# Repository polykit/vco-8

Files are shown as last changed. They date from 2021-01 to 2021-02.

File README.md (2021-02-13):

# Polykit Octo VCO aka VCO-8

This repository contains Kicad schematics and PCB layout for an octo 1V/oct VCO. It is based on [this design](https://github.com/polykit/vco-1).

Here you can listen to some short examples how it sounds: [example 1](https://soundcloud.com/polykit/polykit-octo-vco) [example 2](https://soundcloud.com/polykit/polykit-oxcto-vco-2)

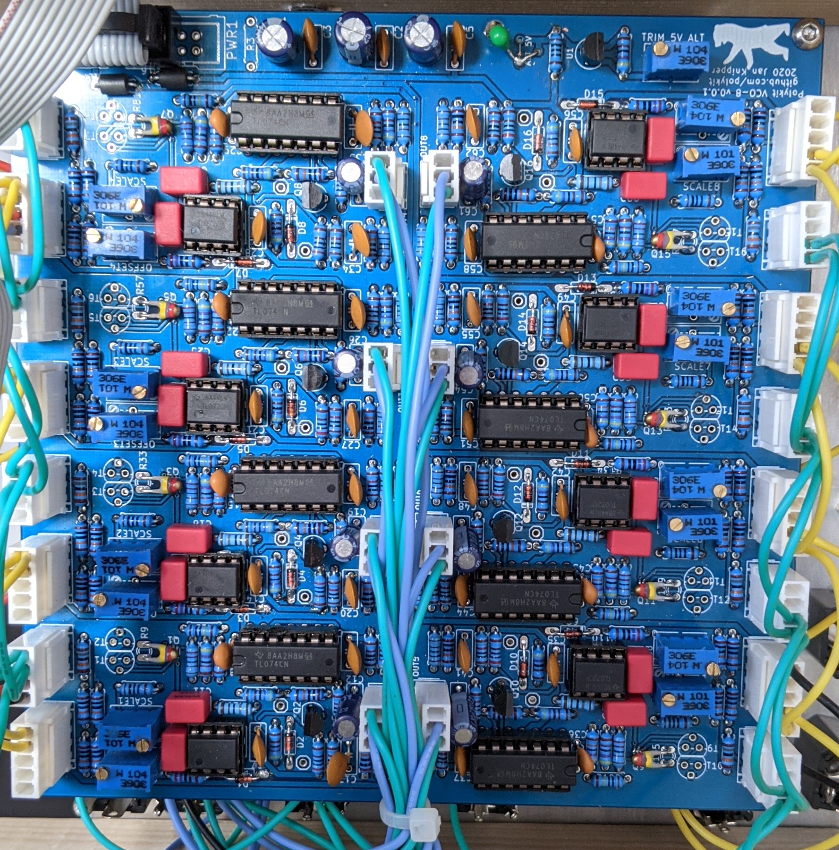
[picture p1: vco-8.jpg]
Polykit Octo VCO


# Building instructions

Building it is really straight forward. I suggest starting with components with the lowest height, eg. all SMD components, all diodes, all resistors and so on. Put all of one kind in place at the same time, eg. all 100k resistors. This helps to reduce problems while building it. If you want to try it out it is maybe a good idea to build the [single VCO](https://github.com/polykit/vco-1) version first.

You need either a pair of matched 2N3904s or one BC847BS transistor pair in a SMD package per VCO. I have very good tracking results with the BC847BS and not so good results with the 2N3904s. But maybe this is because of my poor matching. Bend the legs of the NTCs so that they are as close as possbile to the transistors.

## Powering

There are two powering options. First is 16-pin Eurorack with +12V, -12V and +5V. Second one is a 10-pin Eurorack with +12V and -12V and an additional TL431 for precise +5V supply. Make sure to put a jumper to `5V_ALT` and leave out `R3` if you opted for the latter. There is a testpoint `TP` where you can measure while adjusting `TRIM_5V_ALT` to +5.00V. I recommend the second option because of it's precision.

## Tuning

Use the power supply that you are going to use later on for tuning. Otherwise you might need to tune it again. I used a tuning device for this but also a tuning app for your mobile will work just fine. This is how I tuned the oscillators:

* Turn it on and wait at least 15 minutes before you start tuning
* Tune all oscillators roughly to a base note, eg. `C4`. Do this by applying the correct CV input and adjusting the offset trim pot.
* Next is to get the right scale. Start with the first oscillator and adjust scale until you have the correct interval between two notes, eg. your base note `C4` and `D4`. While changing scale overall tuning will change, so go back to your base note from time to time by adjusting the offset. When your are quite close to the correct scale fine tune it for a whole ocatve, eg. using notes `C4` and `C5`. Proceed with the next oscillator.
* Start again with the first oscillator until everything is in tune. Usually you only need to adjust offset for this.

## Tweaks

* Use ferrite beads or just jumpers instead of the 10R resistors for R3, R4 and R5. There is a significant voltage drop over the resistors leading to a lower peak-to-peak amplitude.
* Use 22µ polarized caps instead of 1µ non-polarized ones. The positive side (+) of the cap is torwards the op-amp and negative (-) to the output. I had the impression that it gives you a nicer ramp signal on the output.

## BOM

|Designator|Quantity |Designation|
|---|---|---|
|U1 |1 |TL431LP*** |
|TRIM_5V_ALT, OFFSET8, OFFSET7, OFFSET6, OFFSET5, OFFSET4, OFFSET3, OFFSET2, OFFSET1|9 |100k |
|R197, R36, R180, R156, R132, R108, R84, R60, R12|9 |47k |
|R196, R182, R158, R134, R110, R86, R62, R38, R14|9 |270 |
|C16, C21, C58, C56, C51, C49, C44, C42, C37, C35, C30, C28, C14, C2, C5, C3, C23, C7, C9|19 |100n |
|C22, C57, C50, C43, C36, C29, C15, C8|8 |1n |
|R50, R195, R194, R171, R170, R147, R146, R123, R122, R99, R98, R75, R74, R51, R27, R26|16 |1k |
|R33, R177, R153, R129, R105, R81, R57, R9|8 |4k7 NTC |
|T16, T15, T14, T13, T12, T11, T10, T9, T8, T7, T6, T5, T4, T3, T1, T2|16 |2N3904* |
|SCALE8, SCALE7, SCALE6, SCALE5, SCALE4, SCALE3, SCALE2, SCALE1|8 |100 |
|R193, R184, R175, R174, R173, R172, R169, R160, R151, R150, R149, R148, R145, R136, R127, R126, R125, R124, R121, R112, R103, R102, R101, R100, R97, R88, R79, R78, R77, R76, R73, R64, R55, R31, R30, R54, R53, R52, R49, R40, R29, R28, R6, R7, R2, R16, R1, R25|48 |100k |
|R192, R186, R176, R168, R162, R152, R144, R138, R128, R120, R114, R104, R96, R90, R80, R72, R66, R56, R32, R48, R42, R24, R8, R18|24 |4k7 |
|R191, R189, R187, R167, R165, R163, R143, R141, R139, R119, R117, R115, R95, R93, R91, R71, R69, R67, R47, R45, R43, R19, R21, R23|24 |10k |
|R190, R166, R142, R118, R94, R70, R46, R22|8 |2k |
|R188, R164, R140, R116, R92, R68, R44, R20|8 |1k8 |
|R185, R161, R137, R113, R89, R65, R41, R17|8 |470k |
|R183, R159, R135, R111, R87, R63, R39, R15|8 |180k |
|R181, R157, R133, R109, R85, R61, R37, R13|8 |1M |
|R179, R155, R131, R107, R83, R59, R35, R11|8 |100* |
|R178, R154, R130, R106, R82, R58, R34, R10|8 |2k2 |
|Q16, Q14, Q12, Q10, Q8, Q6, Q4, Q2|8 |BS170 |
|Q15, Q13, Q11, Q9, Q7, Q5, Q3, Q1|8 |BC847BS* |
|IC16, IC14, IC12, IC10, IC8, IC6, IC2, IC4|8 |TL072P |
|IC15, IC13, IC11, IC9, IC7, IC5, IC1, IC3|8 |TL074P |
|D16, D15, D14, D13, D12, D11, D10, D9, D8, D7, D6, D5, D4, D3, D2, D1|16 |1N4148 |
|C62, C55, C48, C41, C34, C27, C20, C13|8 |10n |
|C61, C54, C47, C40, C33, C19, C26, C12|8 |1µ** |
|C60, C53, C46, C39, C32, C18, C25, C11|8 |100p** |
|C59, C52, C45, C38, C31, C17, C24, C10|8 |1n** |
|C6, C4, C1  |3 |10µ polarized |
|R4, R5, R3  |3 |10 |
|PWR1 |1 |ML16 or ML10***| 

\* Use either matched pairs of 2N3904s or BC847BS dual transistors. Use 120R instead of 100R for R179, R155, R131, R107, R83, R59, R35 and R11 when you are going for the 2N3904s.

\** Use polypropylene or similar caps

\*** See powering options. Leave out U1, R196, R197 and TRIM_5V_ALT if you opted for 16-pin Eurorack supply with +5V in place.

# References

https://github.com/polykit/vco-1

https://www.diodes.com/assets/Datasheets/ds30222.pdf

https://www.ti.com/lit/ds/symlink/tl431.pdf

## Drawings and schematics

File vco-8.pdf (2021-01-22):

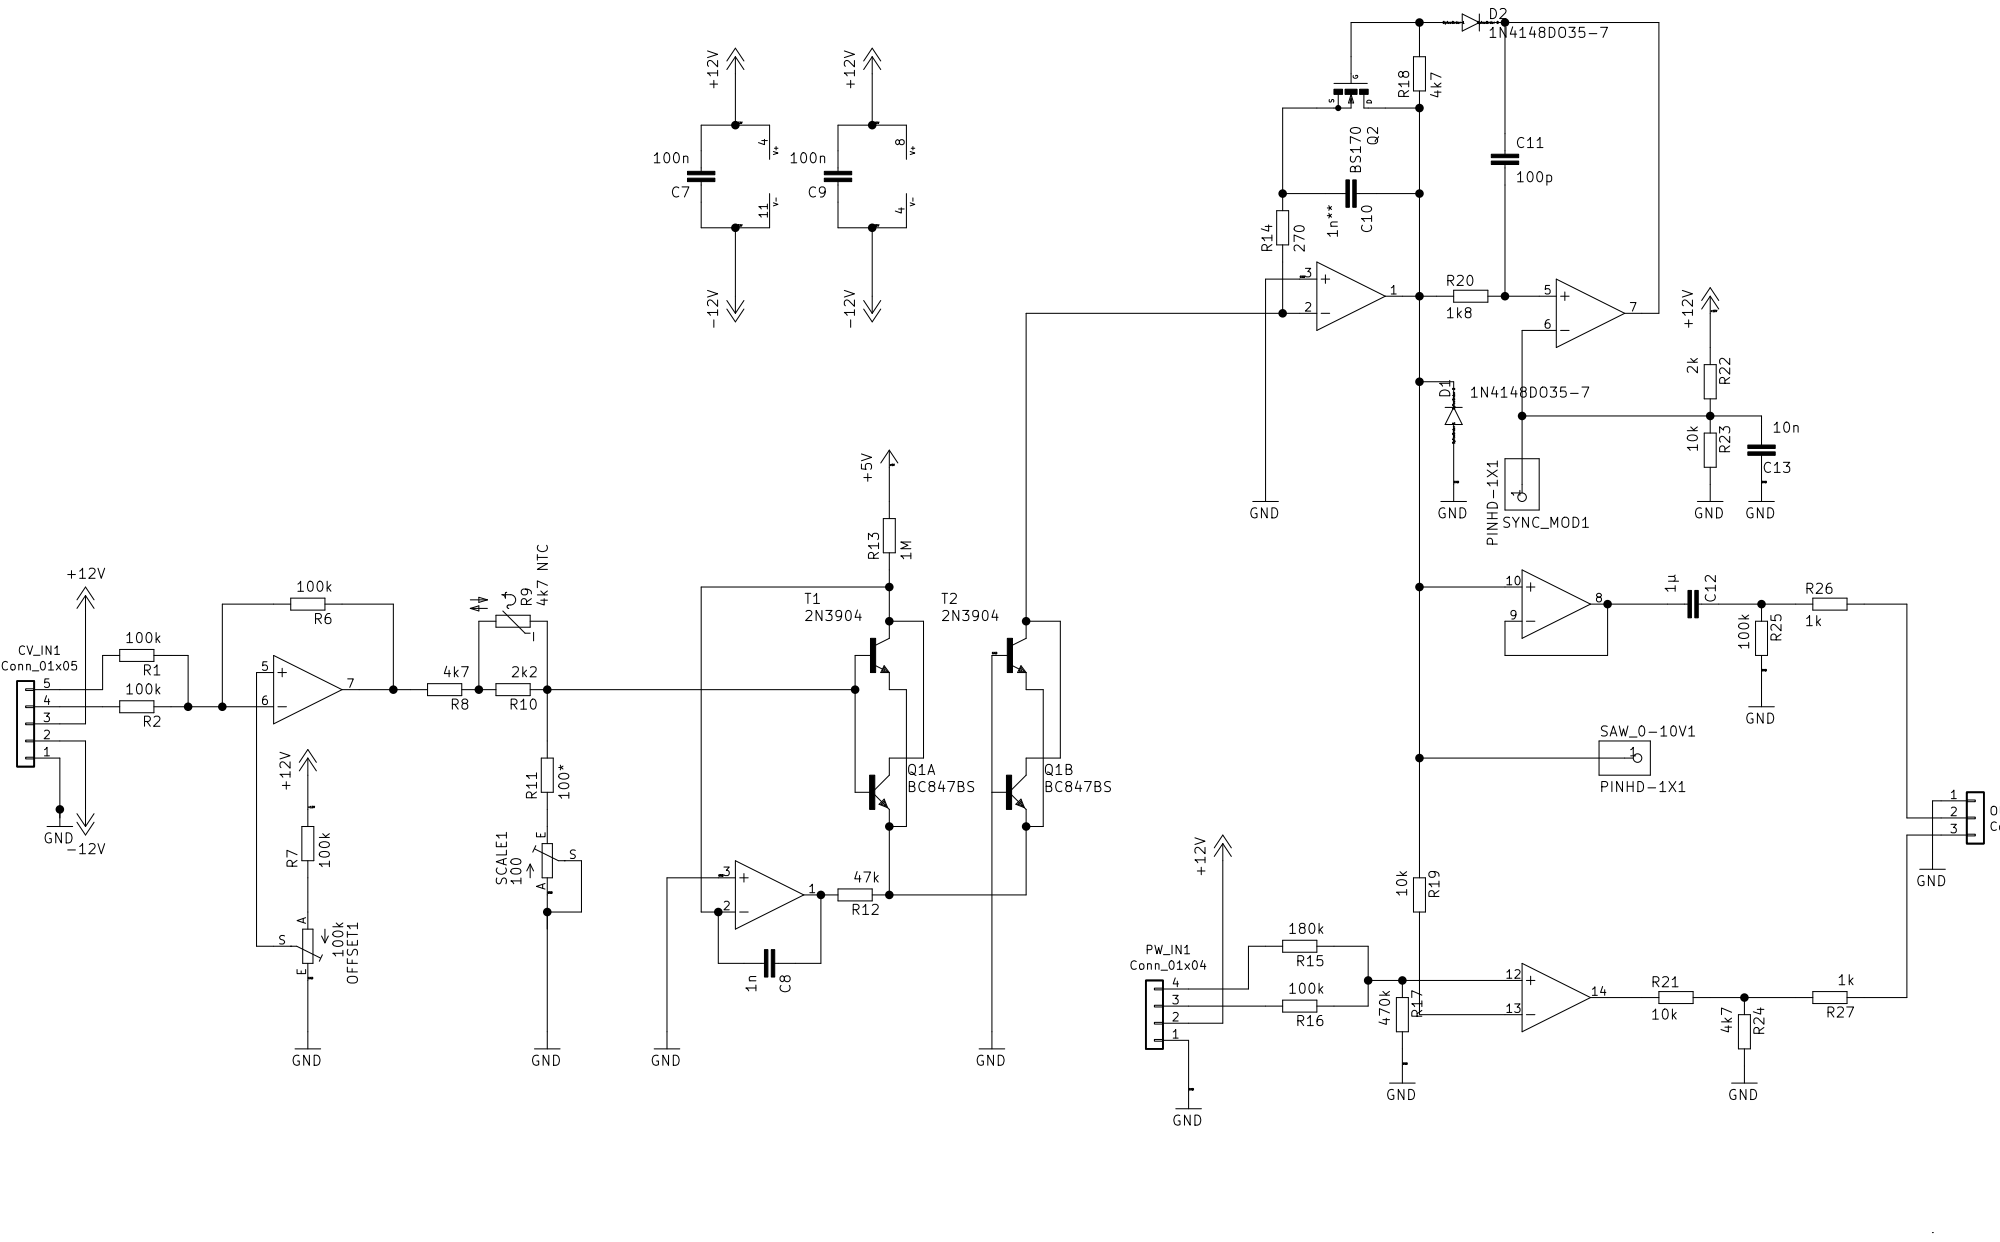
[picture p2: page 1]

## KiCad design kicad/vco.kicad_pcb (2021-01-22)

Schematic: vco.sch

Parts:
C1, C4, C6: 47µ; E2,5-5
C2, C3, C5: 100n; C050-030X075
PWR1: ML16
R3, R4, R5: 10; 0207_7
R196: 270; 0207_7
R197: 47k; 0207_7
TP1: Conn_01x01; 1X01
TRIM_5V1: 100k; S64YW
U1: TL431LP; TO-92_Inline

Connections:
5V_ALT: R196.2, R197.1, TP1.1, U1.3 (K); also elsewhere on the board
+5V: C1.+, C3.2, R3.1; also elsewhere on the board
+12V: C5.2, C6.+, R4.1, R196.1; also elsewhere on the board
-12V: C2.2, C4.-, R5.1; also elsewhere on the board
GND: C1.-, C2.1, C3.1, C4.+, C5.1, C6.-, PWR1.3, PWR1.4, PWR1.5, PWR1.6, PWR1.7, PWR1.8, TRIM_5V1.E, TRIM_5V1.S, U1.2 (A); also elsewhere on the board
unnamed: PWR1.1, PWR1.2, R5.2
unnamed: PWR1.9, PWR1.10, R4.2
unnamed: PWR1.11, PWR1.12, R3.2
unnamed: R197.2, TRIM_5V1.A, U1.1 (REF)

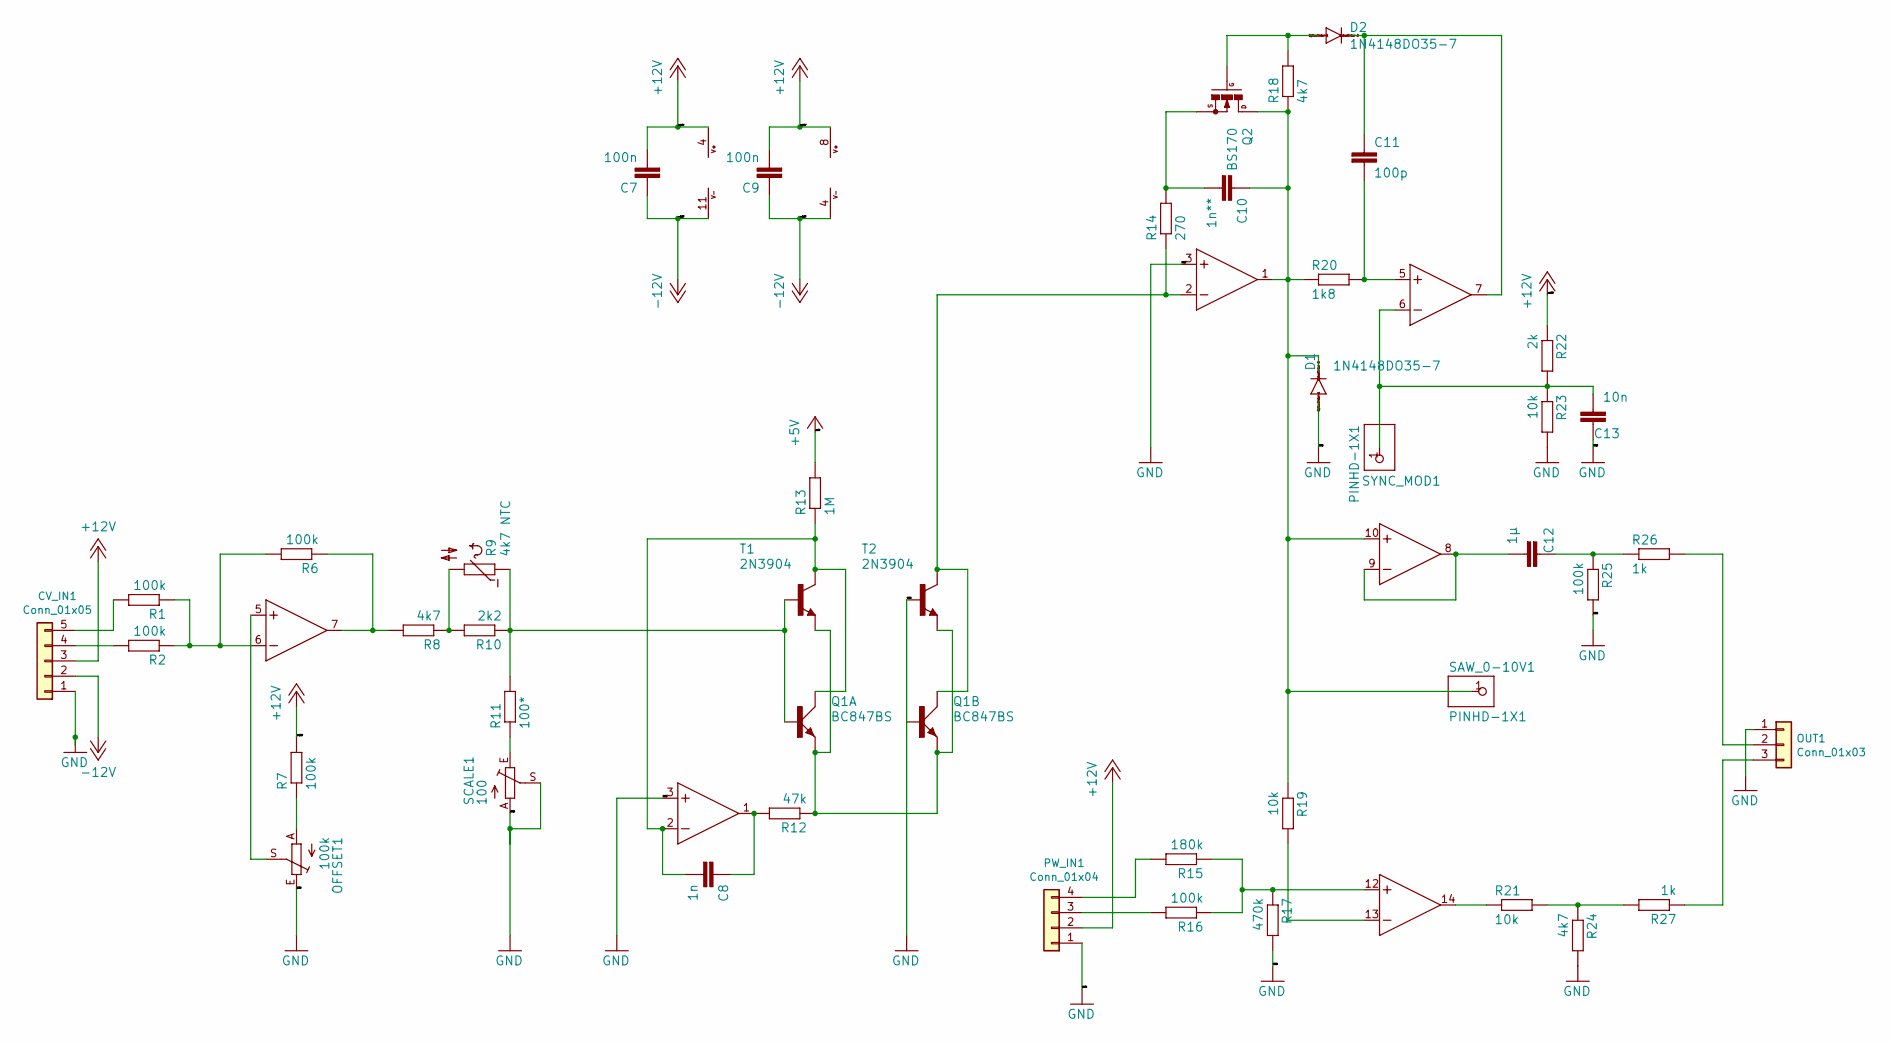
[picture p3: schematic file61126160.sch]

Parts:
C7, C9: 100n; C050-030X075
C8: 1n; C050-024X044
C10: 1n**; C050-030X075
C11: 100p; C050-030X075
C12: 1µ; C050-030X075
C13: 10n; C050-030X075
CV_IN1: Conn_01x05; Molex_KK-254_AE-6410-05A_1x05_P2.54mm_Vertical
D1, D2: 1N4148DO35-7; DO35-7
IC1: TL074P; DIL14
IC2: TL072P; DIL08
OFFSET1: 100k; S64YW
OUT1: Conn_01x03; Molex_KK-254_AE-6410-03A_1x03_P2.54mm_Vertical
PW_IN1: Conn_01x04; Molex_KK-254_AE-6410-04A_1x04_P2.54mm_Vertical
Q1: BC847BS; SOT363_PHILIPS
Q2: BS170; SOT54E
R1, R2, R6, R7, R16, R25: 100k; 0207_7
R8, R18, R24: 4k7; 0207_7
R9: 4k7 NTC; P640
R10: 2k2; 0207_7
R11: 100*; 0207_7
R12: 47k; 0207_7
R13: 1M; 0207_7
R14: 270; 0207_7
R15: 180k; 0207_7
R17: 470k; 0207_7
R19, R21, R23: 10k; 0207_7
R20: 1k8; 0207_7
R22: 2k; 0207_7
R26, R27: 1k; 0207_7
SAW_0-10V1: PINHD-1X1; 1X01
SCALE1: 100; S64YW
SYNC_MOD1: PINHD-1X1; 1X01
T1, T2: 2N3904; TO92

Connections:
+5V: R13.2; also elsewhere on the board
+12V: C7.2, C9.2, CV_IN1.3, IC1.4 (V+), IC2.8 (V+), PW_IN1.2, R7.2, R22.1; also elsewhere on the board
-12V: C7.1, C9.1, CV_IN1.2, IC1.11 (V-), IC2.4 (V-); also elsewhere on the board
GND: C13.1, CV_IN1.1, D1.A, IC1.3 (+IN), IC2.3 (+IN), OFFSET1.E, OUT1.1, PW_IN1.1, Q1.5 (B), R17.2, R23.2, R24.2, R25.2, SCALE1.A, SCALE1.S, T2.2 (B); also elsewhere on the board
unnamed: C8.1, IC1.1 (OUT), R12.2
unnamed: C8.2, IC1.2 (-IN), Q1.6 (C), R13.1, T1.1 (C)
unnamed: C10.1, D1.C, IC1.10 (+IN), IC2.1 (OUT), Q2.D, R18.1, R19.1, R20.1, SAW_0-10V1.1
unnamed: C10.2, Q2.S, R14.2
unnamed: C11.1, D2.C, IC2.7 (OUT)
unnamed: C11.2, IC2.5 (+IN), R20.2
unnamed: C12.1, R25.1, R26.1
unnamed: C12.2, IC1.8 (OUT), IC1.9 (-IN)
unnamed: C13.2, IC2.6 (-IN), R22.2, R23.1, SYNC_MOD1.1
unnamed: CV_IN1.4, R2.2
unnamed: CV_IN1.5, R1.2
unnamed: D2.A, Q2.G, R18.2
unnamed: IC1.5 (+IN), OFFSET1.S
unnamed: IC1.6 (-IN), R1.1, R2.1, R6.2
unnamed: IC1.7 (OUT), R6.1, R8.2
unnamed: IC1.12 (+IN), R15.1, R16.1, R17.1
unnamed: IC1.13 (-IN), R19.2
unnamed: IC1.14 (OUT), R21.1
unnamed: IC2.2 (-IN), Q1.3 (C), R14.1, T2.1 (C)
unnamed: OFFSET1.A, R7.1
unnamed: OUT1.2, R26.2
unnamed: OUT1.3, R27.1
unnamed: PW_IN1.3, R16.2
unnamed: PW_IN1.4, R15.2
unnamed: Q1.1 (E), Q1.4 (E), R12.1, T1.3 (E), T2.3 (E)
unnamed: Q1.2 (B), R9.1, R10.1, R11.2, T1.2 (B)
unnamed: R8.1, R9.2, R10.2
unnamed: R11.1, SCALE1.E
unnamed: R21.2, R24.1, R27.2

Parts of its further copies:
C14, C16, C21, C23, C28, C30, C35, C37, C42, C44, C49, C51, C56, C58: 100n; C050-030X075
C15, C29, C36, C43, C50, C57: 1n; C050-024X044
C17, C24, C31, C38, C45, C52, C59: 1n**; C050-030X075
C18, C25, C32, C39, C46, C53, C60: 100p; C050-030X075
C19, C33, C40, C47, C54, C61: 1µ; C050-030X075
C27, C34, C41, C48, C55, C62: 10n; C050-030X075
CV_IN2, CV_IN3, CV_IN4, CV_IN5, CV_IN6, CV_IN7, CV_IN8: Conn_01x05; Molex_KK-254_AE-6410-05A_1x05_P2.54mm_Vertical
D3, D4, D5, D6, D7, D8, D9, D10, D11, D12, D13, D14, D15, D16: 1N4148DO35-7; DO35-7
IC3, IC5, IC7, IC9, IC11, IC13, IC15: TL074P; DIL14
IC4, IC6, IC8, IC10, IC12, IC14, IC16: TL072P; DIL08
OFFSET2, OFFSET3, OFFSET4, OFFSET5, OFFSET6, OFFSET7, OFFSET8: 100k; S64YW
OUT2, OUT3, OUT4, OUT5, OUT6, OUT7, OUT8: Conn_01x03; Molex_KK-254_AE-6410-03A_1x03_P2.54mm_Vertical
PW_IN2, PW_IN3, PW_IN4, PW_IN5, PW_IN6, PW_IN7, PW_IN8: Conn_01x04; Molex_KK-254_AE-6410-04A_1x04_P2.54mm_Vertical
Q3, Q5, Q7, Q9, Q11, Q13, Q15: BC847BS; SOT363_PHILIPS
Q4, Q6, Q8, Q10, Q12, Q14, Q16: BS170; SOT54E
R28, R29, R30, R31, R52, R53, R55, R64, R73, R76, R77, R78, R79, R88, R97, R100, R101, R102, R103, R112, R121, R124, R125, R126, R127, R136, R145, R148, R149, R150, R151, R160, R169, R172, R173, R174, R175, R184, R193: 100k; 0207_7
R32, R56, R66, R72, R80, R90, R96, R104, R114, R120, R128, R138, R144, R152, R162, R168, R176, R186, R192: 4k7; 0207_7
R33, R57, R81, R105, R129, R153, R177: 4k7 NTC; P640
R34, R58, R82, R106, R130, R154, R178: 2k2; 0207_7
R37, R61, R85, R109, R133, R157, R181: 1M; 0207_7
R38, R62, R86, R110, R134, R158, R182: 270; 0207_7
R39, R63, R87, R111, R135, R159, R183: 180k; 0207_7
R43, R45, R67, R69, R71, R91, R93, R95, R115, R117, R119, R139, R141, R143, R163, R165, R167, R187, R189, R191: 10k; 0207_7
R44, R68, R92, R116, R140, R164, R188: 1k8; 0207_7
R50, R51, R74, R75, R98, R99, R122, R123, R146, R147, R170, R171, R194, R195: 1k; 0207_7
R59, R83, R107, R131, R155, R179: 100*; 0207_7
R60, R84, R108, R132, R156, R180: 47k; 0207_7
R65, R89, R113, R137, R161, R185: 470k; 0207_7
R70, R94, R118, R142, R166, R190: 2k; 0207_7
SAW_0-10V2, SAW_0-10V3, SAW_0-10V4, SAW_0-10V5, SAW_0-10V6, SAW_0-10V7, SAW_0-10V8: PINHD-1X1; 1X01
SCALE2, SCALE3, SCALE4, SCALE5, SCALE6, SCALE7, SCALE8: 100; S64YW
SYNC_MOD2, SYNC_MOD3, SYNC_MOD4, SYNC_MOD5, SYNC_MOD6, SYNC_MOD7, SYNC_MOD8: PINHD-1X1; 1X01
T3, T4, T5, T6, T7, T8, T9, T10, T11, T12, T13, T14, T15, T16: 2N3904; TO92

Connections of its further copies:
+5V: R37.2, R61.2, R85.2, R109.2, R133.2, R157.2, R181.2; also elsewhere on the board
+12V: C14.2, C16.2, C21.2, C23.2, C28.2, C30.2, C35.2, C37.2, C42.2, C44.2, C49.2, C51.2, C56.2, C58.2, CV_IN2.3, CV_IN3.3, CV_IN4.3, CV_IN5.3, CV_IN6.3, CV_IN7.3, CV_IN8.3, IC3.4 (V+), IC4.8 (V+), IC5.4 (V+), IC6.8 (V+), IC7.4 (V+), IC8.8 (V+), IC9.4 (V+), IC10.8 (V+), IC11.4 (V+), IC12.8 (V+), IC13.4 (V+), IC14.8 (V+), IC15.4 (V+), IC16.8 (V+), PW_IN2.2, PW_IN3.2, PW_IN4.2, PW_IN5.2, PW_IN6.2, PW_IN7.2, PW_IN8.2, R31.2, R55.2, R70.1, R79.2, R94.1, R103.2, R118.1, R127.2, R142.1, R151.2, R166.1, R175.2, R190.1; also elsewhere on the board
-12V: C14.1, C16.1, C21.1, C23.1, C28.1, C30.1, C35.1, C37.1, C42.1, C44.1, C49.1, C51.1, C56.1, C58.1, CV_IN2.2, CV_IN3.2, CV_IN4.2, CV_IN5.2, CV_IN6.2, CV_IN7.2, CV_IN8.2, IC3.11 (V-), IC4.4 (V-), IC5.11 (V-), IC6.4 (V-), IC7.11 (V-), IC8.4 (V-), IC9.11 (V-), IC10.4 (V-), IC11.11 (V-), IC12.4 (V-), IC13.11 (V-), IC14.4 (V-), IC15.11 (V-), IC16.4 (V-); also elsewhere on the board
GND: C27.1, C34.1, C41.1, C48.1, C55.1, C62.1, CV_IN2.1, CV_IN3.1, CV_IN4.1, CV_IN5.1, CV_IN6.1, CV_IN7.1, CV_IN8.1, D3.A, D5.A, D7.A, D9.A, D11.A, D13.A, D15.A, IC3.3 (+IN), IC4.3 (+IN), IC5.3 (+IN), IC6.3 (+IN), IC7.3 (+IN), IC8.3 (+IN), IC9.3 (+IN), IC10.3 (+IN), IC11.3 (+IN), IC12.3 (+IN), IC13.3 (+IN), IC14.3 (+IN), IC15.3 (+IN), IC16.3 (+IN), OFFSET2.E, OFFSET3.E, OFFSET4.E, OFFSET5.E, OFFSET6.E, OFFSET7.E, OFFSET8.E, OUT2.1, OUT3.1, OUT4.1, OUT5.1, OUT6.1, OUT7.1, OUT8.1, PW_IN2.1, PW_IN3.1, PW_IN4.1, PW_IN5.1, PW_IN6.1, PW_IN7.1, PW_IN8.1, Q3.5 (B), Q5.5 (B), Q7.5 (B), Q9.5 (B), Q11.5 (B), Q13.5 (B), Q15.5 (B), R65.2, R71.2, R72.2, R73.2, R89.2, R95.2, R96.2, R97.2, R113.2, R119.2, R120.2, R121.2, R137.2, R143.2, R144.2, R145.2, R161.2, R167.2, R168.2, R169.2, R185.2, R191.2, R192.2, R193.2, SCALE2.A, SCALE2.S, SCALE3.A, SCALE3.S, SCALE4.A, SCALE4.S, SCALE5.A, SCALE5.S, SCALE6.A, SCALE6.S, SCALE7.A, SCALE7.S, SCALE8.A, SCALE8.S, T4.2 (B), T6.2 (B), T8.2 (B), T10.2 (B), T12.2 (B), T14.2 (B), T16.2 (B); also elsewhere on the board
unnamed 14: C15.1, IC3.1 (OUT); also elsewhere on the board
unnamed: C15.2, IC3.2 (-IN), Q3.6 (C), R37.1, T3.1 (C)
unnamed 16: C17.1, D3.C, IC3.10 (+IN), IC4.1 (OUT), Q4.D, R43.1, R44.1, SAW_0-10V2.1; also elsewhere on the board
unnamed: C17.2, Q4.S, R38.2
unnamed: C18.1, D4.C, IC4.7 (OUT)
unnamed: C18.2, IC4.5 (+IN), R44.2
unnamed 20: C19.1, R50.1; also elsewhere on the board
unnamed: C19.2, IC3.8 (OUT), IC3.9 (-IN)
unnamed 22: IC4.6 (-IN), SYNC_MOD2.1; also elsewhere on the board
unnamed 23: IC5.1 (OUT), R60.2; also elsewhere on the board
unnamed 24: IC5.2 (-IN), Q5.6 (C), R61.1, T5.1 (C); also elsewhere on the board
unnamed: C24.1, D5.C, IC5.10 (+IN), IC6.1 (OUT), Q6.D, R66.1, R67.1, R68.1, SAW_0-10V3.1
unnamed: C24.2, Q6.S, R62.2
unnamed: C25.1, D6.C, IC6.7 (OUT)
unnamed: C25.2, IC6.5 (+IN), R68.2
unnamed 29: R73.1, R74.1; also elsewhere on the board
unnamed 30: IC5.8 (OUT), IC5.9 (-IN); also elsewhere on the board
unnamed: C27.2, IC6.6 (-IN), R70.2, R71.1, SYNC_MOD3.1
unnamed: C29.1, IC7.1 (OUT), R84.2
unnamed: C29.2, IC7.2 (-IN), Q7.6 (C), R85.1, T7.1 (C)
unnamed: C31.1, D7.C, IC7.10 (+IN), IC8.1 (OUT), Q8.D, R90.1, R91.1, R92.1, SAW_0-10V4.1
unnamed: C31.2, Q8.S, R86.2
unnamed: C32.1, D8.C, IC8.7 (OUT)
unnamed: C32.2, IC8.5 (+IN), R92.2
unnamed: C33.1, R97.1, R98.1
unnamed: C33.2, IC7.8 (OUT), IC7.9 (-IN)
unnamed: C34.2, IC8.6 (-IN), R94.2, R95.1, SYNC_MOD4.1
unnamed: C36.1, IC9.1 (OUT), R108.2
unnamed: C36.2, IC9.2 (-IN), Q9.6 (C), R109.1, T9.1 (C)
unnamed: C38.1, D9.C, IC9.10 (+IN), IC10.1 (OUT), Q10.D, R114.1, R115.1, R116.1, SAW_0-10V5.1
unnamed: C38.2, Q10.S, R110.2
unnamed: C39.1, D10.C, IC10.7 (OUT)
unnamed: C39.2, IC10.5 (+IN), R116.2
unnamed: C40.1, R121.1, R122.1
unnamed: C40.2, IC9.8 (OUT), IC9.9 (-IN)
unnamed: C41.2, IC10.6 (-IN), R118.2, R119.1, SYNC_MOD5.1
unnamed: C43.1, IC11.1 (OUT), R132.2
unnamed: C43.2, IC11.2 (-IN), Q11.6 (C), R133.1, T11.1 (C)
unnamed: C45.1, D11.C, IC11.10 (+IN), IC12.1 (OUT), Q12.D, R138.1, R139.1, R140.1, SAW_0-10V6.1
unnamed: C45.2, Q12.S, R134.2
unnamed: C46.1, D12.C, IC12.7 (OUT)
unnamed: C46.2, IC12.5 (+IN), R140.2
unnamed: C47.1, R145.1, R146.1
unnamed: C47.2, IC11.8 (OUT), IC11.9 (-IN)
unnamed: C48.2, IC12.6 (-IN), R142.2, R143.1, SYNC_MOD6.1
unnamed: C50.1, IC13.1 (OUT), R156.2
unnamed: C50.2, IC13.2 (-IN), Q13.6 (C), R157.1, T13.1 (C)
unnamed: C52.1, D13.C, IC13.10 (+IN), IC14.1 (OUT), Q14.D, R162.1, R163.1, R164.1, SAW_0-10V7.1
unnamed: C52.2, Q14.S, R158.2
unnamed: C53.1, D14.C, IC14.7 (OUT)
unnamed: C53.2, IC14.5 (+IN), R164.2
unnamed: C54.1, R169.1, R170.1
unnamed: C54.2, IC13.8 (OUT), IC13.9 (-IN)
unnamed: C55.2, IC14.6 (-IN), R166.2, R167.1, SYNC_MOD7.1
unnamed: C57.1, IC15.1 (OUT), R180.2
unnamed: C57.2, IC15.2 (-IN), Q15.6 (C), R181.1, T15.1 (C)
unnamed: C59.1, D15.C, IC15.10 (+IN), IC16.1 (OUT), Q16.D, R186.1, R187.1, R188.1, SAW_0-10V8.1
unnamed: C59.2, Q16.S, R182.2
unnamed: C60.1, D16.C, IC16.7 (OUT)
unnamed: C60.2, IC16.5 (+IN), R188.2
unnamed: C61.1, R193.1, R194.1
unnamed: C61.2, IC15.8 (OUT), IC15.9 (-IN)
unnamed: C62.2, IC16.6 (-IN), R190.2, R191.1, SYNC_MOD8.1
unnamed: CV_IN2.4, R29.2
unnamed: CV_IN2.5, R28.2
unnamed: CV_IN3.4, R53.2
unnamed: CV_IN3.5, R52.2
unnamed: CV_IN4.4, R77.2
unnamed: CV_IN4.5, R76.2
unnamed: CV_IN5.4, R101.2
unnamed: CV_IN5.5, R100.2
unnamed: CV_IN6.4, R125.2
unnamed: CV_IN6.5, R124.2
unnamed: CV_IN7.4, R149.2
unnamed: CV_IN7.5, R148.2
unnamed: CV_IN8.4, R173.2
unnamed: CV_IN8.5, R172.2
unnamed 94: D4.A, Q4.G; also elsewhere on the board
unnamed: D6.A, Q6.G, R66.2
unnamed: D8.A, Q8.G, R90.2
unnamed: D10.A, Q10.G, R114.2
unnamed: D12.A, Q12.G, R138.2
unnamed: D14.A, Q14.G, R162.2
unnamed: D16.A, Q16.G, R186.2
unnamed: IC3.5 (+IN), OFFSET2.S
unnamed: IC3.6 (-IN), R28.1, R29.1, R30.2
unnamed: IC3.7 (OUT), R30.1, R32.2
unnamed 111: IC3.12 (+IN), R39.1; also elsewhere on the board
unnamed: IC3.13 (-IN), R43.2
unnamed: IC3.14 (OUT), R45.1
unnamed: IC4.2 (-IN), Q3.3 (C), R38.1, T4.1 (C)
unnamed: IC5.5 (+IN), OFFSET3.S
unnamed 116: IC5.6 (-IN), R52.1, R53.1; also elsewhere on the board
unnamed 117: IC5.7 (OUT), R56.2; also elsewhere on the board
unnamed: IC5.12 (+IN), R63.1, R64.1, R65.1
unnamed: IC5.13 (-IN), R67.2
unnamed: IC5.14 (OUT), R69.1
unnamed: IC6.2 (-IN), Q5.3 (C), R62.1, T6.1 (C)
unnamed: IC7.5 (+IN), OFFSET4.S
unnamed: IC7.6 (-IN), R76.1, R77.1, R78.2
unnamed: IC7.7 (OUT), R78.1, R80.2
unnamed: IC7.12 (+IN), R87.1, R88.1, R89.1
unnamed: IC7.13 (-IN), R91.2
unnamed: IC7.14 (OUT), R93.1
unnamed: IC8.2 (-IN), Q7.3 (C), R86.1, T8.1 (C)
unnamed: IC9.5 (+IN), OFFSET5.S
unnamed: IC9.6 (-IN), R100.1, R101.1, R102.2
unnamed: IC9.7 (OUT), R102.1, R104.2
unnamed: IC9.12 (+IN), R111.1, R112.1, R113.1
unnamed: IC9.13 (-IN), R115.2
unnamed: IC9.14 (OUT), R117.1
unnamed: IC10.2 (-IN), Q9.3 (C), R110.1, T10.1 (C)
unnamed: IC11.5 (+IN), OFFSET6.S
unnamed: IC11.6 (-IN), R124.1, R125.1, R126.2
unnamed: IC11.7 (OUT), R126.1, R128.2
unnamed: IC11.12 (+IN), R135.1, R136.1, R137.1
unnamed: IC11.13 (-IN), R139.2
unnamed: IC11.14 (OUT), R141.1
unnamed: IC12.2 (-IN), Q11.3 (C), R134.1, T12.1 (C)
unnamed: IC13.5 (+IN), OFFSET7.S
unnamed: IC13.6 (-IN), R148.1, R149.1, R150.2
unnamed: IC13.7 (OUT), R150.1, R152.2
unnamed: IC13.12 (+IN), R159.1, R160.1, R161.1
unnamed: IC13.13 (-IN), R163.2
unnamed: IC13.14 (OUT), R165.1
unnamed: IC14.2 (-IN), Q13.3 (C), R158.1, T14.1 (C)
unnamed: IC15.5 (+IN), OFFSET8.S
unnamed: IC15.6 (-IN), R172.1, R173.1, R174.2
unnamed: IC15.7 (OUT), R174.1, R176.2
unnamed: IC15.12 (+IN), R183.1, R184.1, R185.1
unnamed: IC15.13 (-IN), R187.2
unnamed: IC15.14 (OUT), R189.1
unnamed: IC16.2 (-IN), Q15.3 (C), R182.1, T16.1 (C)
unnamed: OFFSET2.A, R31.1
unnamed: OFFSET3.A, R55.1
unnamed: OFFSET4.A, R79.1
unnamed: OFFSET5.A, R103.1
unnamed: OFFSET6.A, R127.1
unnamed: OFFSET7.A, R151.1
unnamed: OFFSET8.A, R175.1
unnamed: OUT2.2, R50.2
unnamed: OUT2.3, R51.1
unnamed: OUT3.2, R74.2
unnamed: OUT3.3, R75.1
unnamed: OUT4.2, R98.2
unnamed: OUT4.3, R99.1
unnamed: OUT5.2, R122.2
unnamed: OUT5.3, R123.1
unnamed: OUT6.2, R146.2
unnamed: OUT6.3, R147.1
unnamed: OUT7.2, R170.2
unnamed: OUT7.3, R171.1
unnamed: OUT8.2, R194.2
unnamed: OUT8.3, R195.1
unnamed 190: PW_IN2.3; also elsewhere on the board
unnamed: PW_IN2.4, R39.2
unnamed: PW_IN3.3, R88.2
unnamed: PW_IN3.4, R87.2
unnamed: PW_IN4.3, R64.2
unnamed: PW_IN4.4, R63.2
unnamed: PW_IN5.3, R112.2
unnamed: PW_IN5.4, R111.2
unnamed: PW_IN6.3, R136.2
unnamed: PW_IN6.4, R135.2
unnamed: PW_IN7.3, R160.2
unnamed: PW_IN7.4, R159.2
unnamed: PW_IN8.3, R184.2
unnamed: PW_IN8.4, R183.2
unnamed 206: Q3.1 (E), Q3.4 (E), T3.3 (E), T4.3 (E); also elsewhere on the board
unnamed 207: Q3.2 (B), R33.1, R34.1, T3.2 (B); also elsewhere on the board
unnamed: Q5.1 (E), Q5.4 (E), R60.1, T5.3 (E), T6.3 (E)
unnamed: Q5.2 (B), R57.1, R58.1, R59.2, T5.2 (B)
unnamed: Q7.1 (E), Q7.4 (E), R84.1, T7.3 (E), T8.3 (E)
unnamed: Q7.2 (B), R81.1, R82.1, R83.2, T7.2 (B)
unnamed: Q9.1 (E), Q9.4 (E), R108.1, T9.3 (E), T10.3 (E)
unnamed: Q9.2 (B), R105.1, R106.1, R107.2, T9.2 (B)
unnamed: Q11.1 (E), Q11.4 (E), R132.1, T11.3 (E), T12.3 (E)
unnamed: Q11.2 (B), R129.1, R130.1, R131.2, T11.2 (B)
unnamed: Q13.1 (E), Q13.4 (E), R156.1, T13.3 (E), T14.3 (E)
unnamed: Q13.2 (B), R153.1, R154.1, R155.2, T13.2 (B)
unnamed: Q15.1 (E), Q15.4 (E), R180.1, T15.3 (E), T16.3 (E)
unnamed: Q15.2 (B), R177.1, R178.1, R179.2, T15.2 (B)
unnamed: R32.1, R33.2, R34.2
unnamed 224: SCALE2.E; also elsewhere on the board
unnamed 225: R45.2, R51.2; also elsewhere on the board
unnamed: R56.1, R57.2, R58.2
unnamed: R59.1, SCALE3.E
unnamed: R69.2, R72.1, R75.2
unnamed: R80.1, R81.2, R82.2
unnamed: R83.1, SCALE4.E
unnamed: R93.2, R96.1, R99.2
unnamed: R104.1, R105.2, R106.2
unnamed: R107.1, SCALE5.E
unnamed: R117.2, R120.1, R123.2
unnamed: R128.1, R129.2, R130.2
unnamed: R131.1, SCALE6.E
unnamed: R141.2, R144.1, R147.2
unnamed: R152.1, R153.2, R154.2
unnamed: R155.1, SCALE7.E
unnamed: R165.2, R168.1, R171.2
unnamed: R176.1, R177.2, R178.2
unnamed: R179.1, SCALE8.E
unnamed: R189.2, R192.1, R195.2

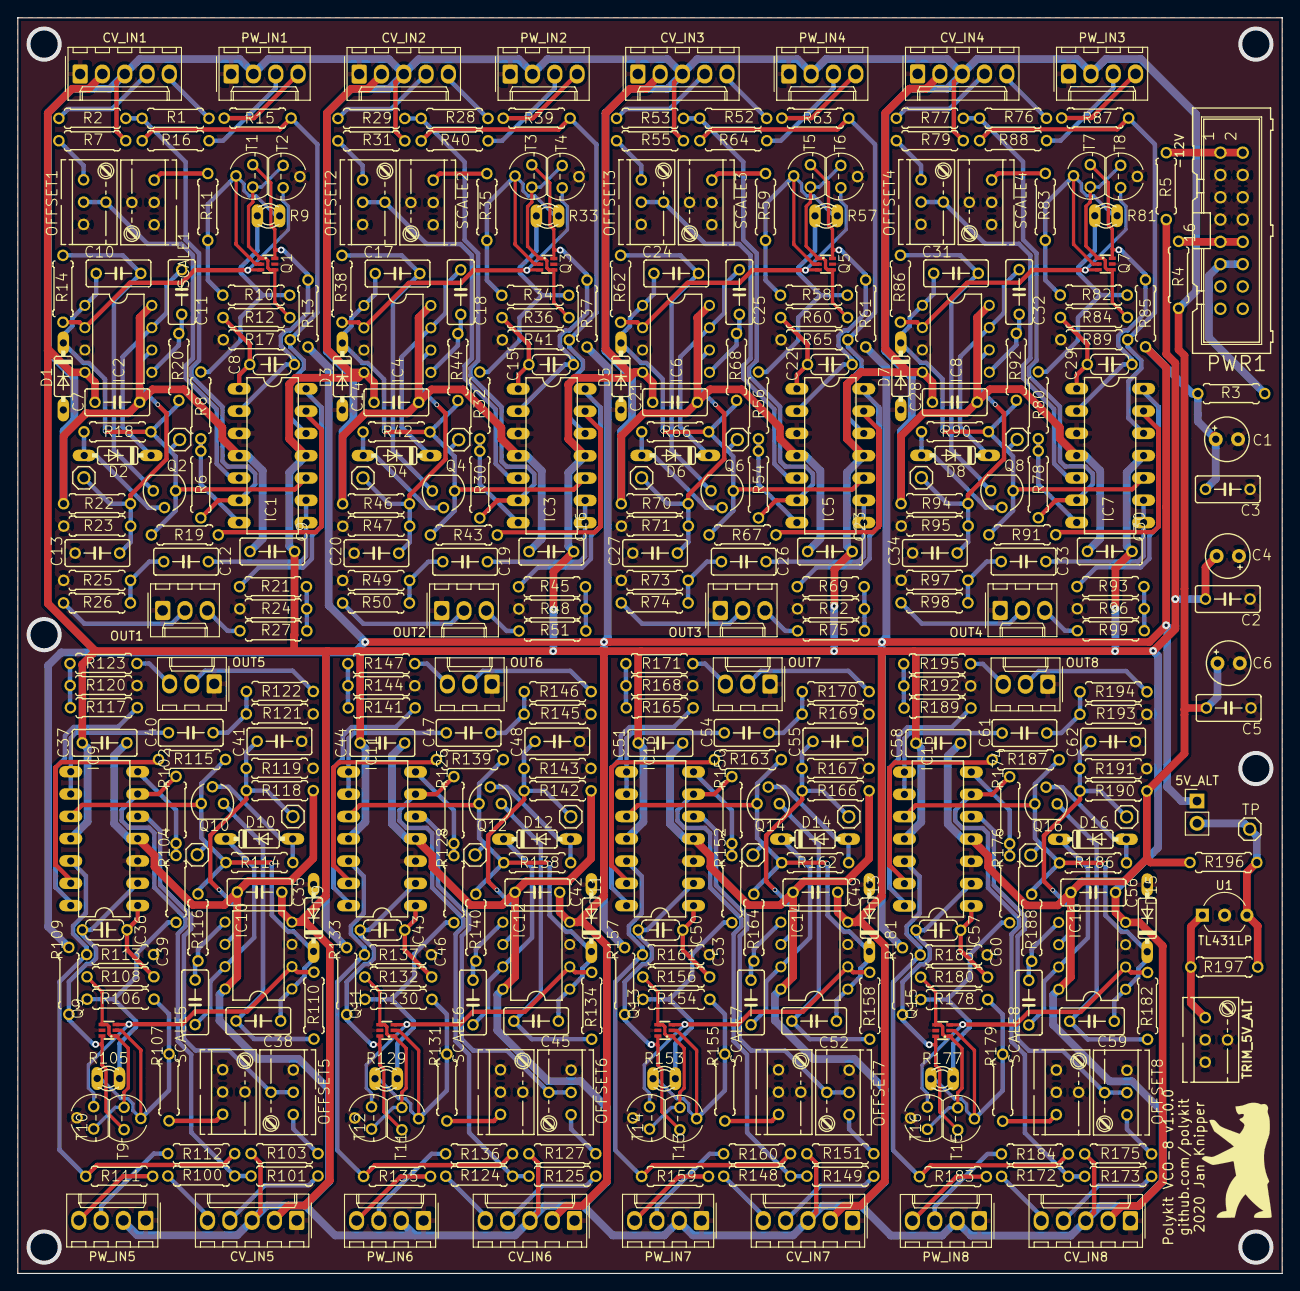
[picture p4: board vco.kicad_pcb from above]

Board: 2 copper layers, 144.0 x 143.0 mm, 384 parts (0 on the bottom side), 241 nets.

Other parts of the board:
5V_ALT: PinHeader_1x02_P2.54mm_Vertical
C20: 10n; C050-030X075
C22: 1n; C050-024X044
C26: 1µ; C050-030X075
R35: 100*; 0207_7
R36: 47k; 0207_7
R40, R49, R54: 100k; 0207_7
R41: 470k; 0207_7
R42, R48: 4k7; 0207_7
R46: 2k; 0207_7
R47: 10k; 0207_7
TP: Conn_01x01; 1X01

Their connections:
5V_ALT: 5V_ALT.2, TP.1; also elsewhere on the board
+5V: 5V_ALT.1; also elsewhere on the board
+12V: R46.1; also elsewhere on the board
GND: C20.1, R41.2, R47.2, R48.2, R49.2; also elsewhere on the board
unnamed 14: R36.2; also elsewhere on the board
unnamed 16: R42.1; also elsewhere on the board
unnamed 20: R49.1; also elsewhere on the board
unnamed 22: C20.2, R46.2, R47.1; also elsewhere on the board
unnamed 23: C22.1; also elsewhere on the board
unnamed 24: C22.2; also elsewhere on the board
unnamed 29: C26.1; also elsewhere on the board
unnamed 30: C26.2; also elsewhere on the board
unnamed 94: R42.2; also elsewhere on the board
unnamed 111: R40.1, R41.1; also elsewhere on the board
unnamed 116: R54.2; also elsewhere on the board
unnamed 117: R54.1; also elsewhere on the board
unnamed 190: R40.2; also elsewhere on the board
unnamed 206: R36.1; also elsewhere on the board
unnamed 207: R35.2; also elsewhere on the board
unnamed 224: R35.1; also elsewhere on the board
unnamed 225: R48.1; also elsewhere on the board

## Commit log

2021-01-22 Initial import
    [file60693ED9.sch, file61126160.sch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]
2021-02-01 Added documentation
    [vco.xls]
2021-02-13 Fix bom
